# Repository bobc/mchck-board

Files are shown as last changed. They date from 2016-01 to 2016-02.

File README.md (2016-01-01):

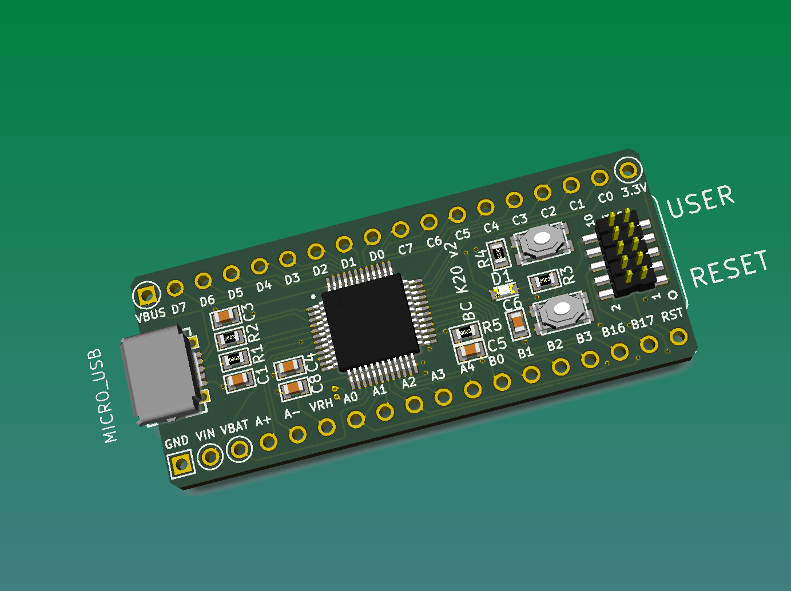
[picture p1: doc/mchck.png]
BC-HCK


About BC-HCK
============

Originally derived from mchck project. I simplified the design a lot to make more of
a bare bones board, and extended the size to get more pins at the edge.
I also incorporated ideas from TinyK20 board, the pin layout is similar (https://github.com/ErichStyger/mcuoneclipse/tree/master/tinyK20).

The schematic design and layout was done using Kicad, a Free Software EDA tool for Linux, Windows and Mac OS (http://kicad-pcb.org/download/). You will need KiCad to open the files - gEDA or Eagle will not work.

Note: this project needs the new stable version of Kicad (4.0.0 or later), previous versions can not read the new files.

KiCad

Copyright
---------
In keeping with original project, licensed with CERN OHL.

Copyright (c) 2016 Bob Cousins  
Copyright (c) 2011,2012 Simon Schubert <2@0x2c.org>

This documentation describes Open Hardware and is licensed under the
CERN OHL v. 1.1.  You may redistribute and modify this documentation
under the terms of the CERN OHL v.1.1.  You can find a copy of the
CERN OHL v.1.1 in the file LICENSE.

Fabrication outputs
-------------------

The gerbers are in the master branch in the gerbers folder.  
The zip file is for submission to ITeadMall, probably could be used for other fab houses.  
The gvp file is for use with gerbv (http://gerbv.geda-project.org/).

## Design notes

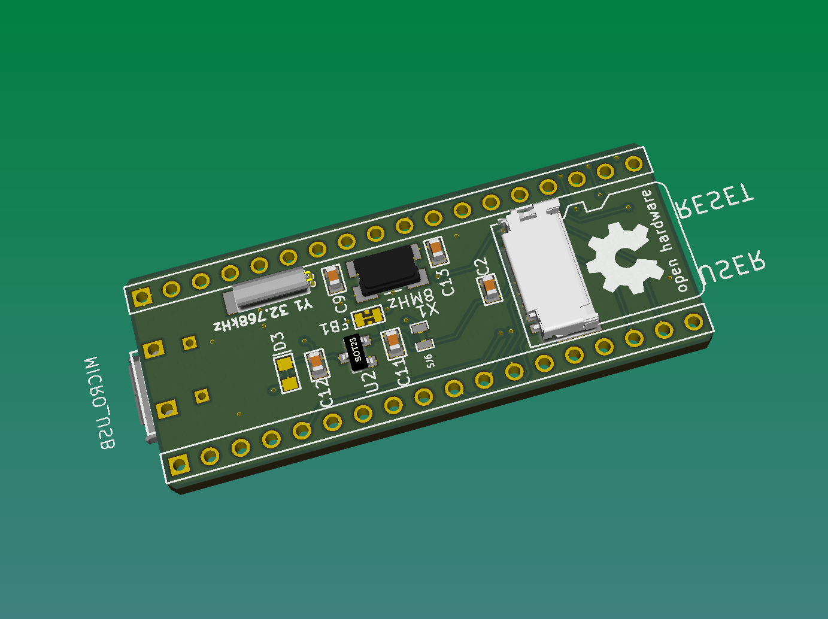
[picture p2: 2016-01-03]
doc/mchck_back.png

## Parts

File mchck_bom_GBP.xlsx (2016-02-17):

Ref | Symbol | Footprint | Value | Quantity | CPN | Manf | MPN | Farnell/Sku | Farnell/Cost | RS Components/Sku | RS Components/Cost
C1 | device:C | mchck:SM0603_Capa | 2.2u | 1 | C0603-2.2uF | Kemet | C0603C225K9PACTU | 1288257 | 0.037 | 147819 | 0.044
C2..C8 | device:C | mchck:SM0603_Capa | 100n | 6 | C0603-100nF | Kemet | C0603C104K3RACTU | 1650835 | 0.046 | 147538 | 0.108
C9..C13 | device:C | mchck:SM0603_Capa | 18pF | 2 | C0603-18pF | Kemet | C0603C180J5GACTU | 1414620 | 0.018 | 147415 | 0.038
C11..C12 | SparkFun:CAP0805 | mchck:SM0603_Capa | 10u | 2 | C0603-A-10uF | Murata | GRM188R60J106ME47D | 1735528 | 0.371 | 7235543 | 0.202
D1 | device:LED | LEDs:LED-0603 | LED | 1 | LED-0603 | Avago | HSMH-C190 | 8554641 | 0.192 | 7166570 | 0.063
D3 | SparkFun:DIODE-SCHOTTKY_ | mchck:SOD-523F-NC | DIODE-SCHOTTKY_ | 1 | D-Schottky-1A | NXP | PMEG3010EB |  |  | 8166842 | 0.070
FB1 | device:FILTER | mchck:SM0603_NC | FILTER | 1 | FB_0603 | TDK | MMZ1608B601CT |  |  | 7865015 | 0.022
G1 | logo:LOGO | mchck:OHW-LOGO-6mm | OHW LOGO | 1
J3 | conn:CONN_01X06 | RMC:USB_MICRO_RMC_FCI | MICRO_USB | 1 | USB-MICRO-FCI | FCI | 10103594-0001LF | 2293752 | 0.393 | 7142347 | 0.426
K1 | opendous:CONN_microSD | RMC:SD_MOLEX_47579-0001-2 | CONN_MICROSD | 1 | SD_MOLEX_47579-0001 | Molex | 47579-0001 |  |  | 7206028 | 0.430
P3..P4 | conn:CONN_01X18 | RMC_pcb_header:pin_header_2.54mm_1x18 | UPPER_PINS | 2 | HDR_1x18_2.54mm | Assmann | AW 108/20-T |  |  | 6742331 | 0.340
P6 | conn:CONN_02X05 | RMC:Pin_Array_5x2_SMT_1.27mm_RMC | JTAG | 1 | HDR_2x5_1.27mm | FCI | 20021121-00010C4LF | 1865279 | 0.492 | 7944584 | 0.524
R1..R2 | device:R | mchck:SM0603 | 33 | 2 | R0603-33R | Vishay | CRCW060333R0FKEA | 1469802RL | 0.021 | 6790239 | 0.022
R3 | device:R | mchck:SM0603 | 1k | 1 | R0603-1k | Vishay | CRCW06031K00FKEA | 1469740 | 0.011 | 6789875 | 0.012
R4..R5 | device:R | mchck:SM0603 | 10k | 2 | R0603-10k | Vishay | CRCW060310K0FKEA | 1469748 | 0.021 | 6789667 | 0.024
S1..S2 | tac_switchsmd_evqp2:TAC_SWITCHSMD_EVQP2 | RMC:SW_C&K_KMR4_ALT | RESET | 2 | SW-KMR4 | C&K | KMR421NGLFS | 1908235 | 0.422 | 7931605 | 0.520
SJ6 | SparkFun:SOLDERJUMPERNC | RMC:SM0603_Bridged | SOLDERJUMPERNC | 1
U1 | MK20LF:MK20LF | mchck:LQFP48 | MK20LF | 1 | IC-MK20DX128-L48 | NXP | MK20DX128VLF5 | 2133571 | 3.260 | 8181104 | 2.665
U2 | RMC:MCP1703_SOT23 | TO_SOT_Packages_SMD:SOT-23 | MCP1703_SOT23 | 1 | REG-MCP1703_SOT23 | Microchip | MCP1703T-3302E/CB | 1439518 | 0.481 | 6694907 | 0.375
X1 | RMC:XTAL_TXC_7V | Crystals:Crystal_SMD_0603_4Pads | 8MHz | 1 | XTAL-8MHz-5x3 | Abracon | ABM3B-8.000MHZ-B2 |  |  | 7031997 | 1.289
Y1 | device:Crystal | w_crystal:crystal_tc-26_horiz | 32.768kHz | 1 | XTAL-TC26H-32k | Fox | NC26LF-327 | 2064057 | 0.301 | 5476979 | 0.290

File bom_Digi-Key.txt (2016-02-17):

399-3362-6-ND,1
399-1281-1-ND,6
399-1052-1-ND,2
490-3896-1-ND,2
516-1420-6-ND,1
609-4050-6-ND,1
609-3695-1-ND,1
541-33.0HDKR-ND,10
541-1.00KHCT-ND,10
541-10.0KHCT-ND,10
KMR421NG LFS-ND,36000
MK20DX128VLF50-ND,1
MCP1703T-3302E/CBCT-ND,1
631-1205-ND,1

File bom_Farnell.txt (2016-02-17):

1288257,10
1650835,6
1414620,2
1735528,2
8554641,1
2293752,1
1865279,1
1469802RL,10
1469740,10
1469748,10
1908235,2
2133571,1
1439518,1
2064057,1

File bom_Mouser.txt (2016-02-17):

80-C0603C225K9P,1
80-C0603C104K3R,6
80-C0603C180J5G,2
81-GRM188R60J106ME47,2
630-HSMH-C190,1
649-10103594-0001LF,1
538-47579-0001,1
649-202112100010C4LF,1
71-CRCW0603-33-E3,2
71-CRCW0603-1.0K-E3,1
71-CRCW0603-10K-E3,2
841-MK20DX128VLF5,1
579-MCP1703T-3302ECB,1
559-NC26-LF,1

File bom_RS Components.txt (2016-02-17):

147819,50
147538,50
147415,50
7235543,25
7166570,10
8166842,60
7865015,100
7142347,5
7206028,1
6742331,5
7944584,5
6790239,50
6789875,50
6789667,50
7931605,2
8181104,2
6694907,10
7031997,10
5476979,10

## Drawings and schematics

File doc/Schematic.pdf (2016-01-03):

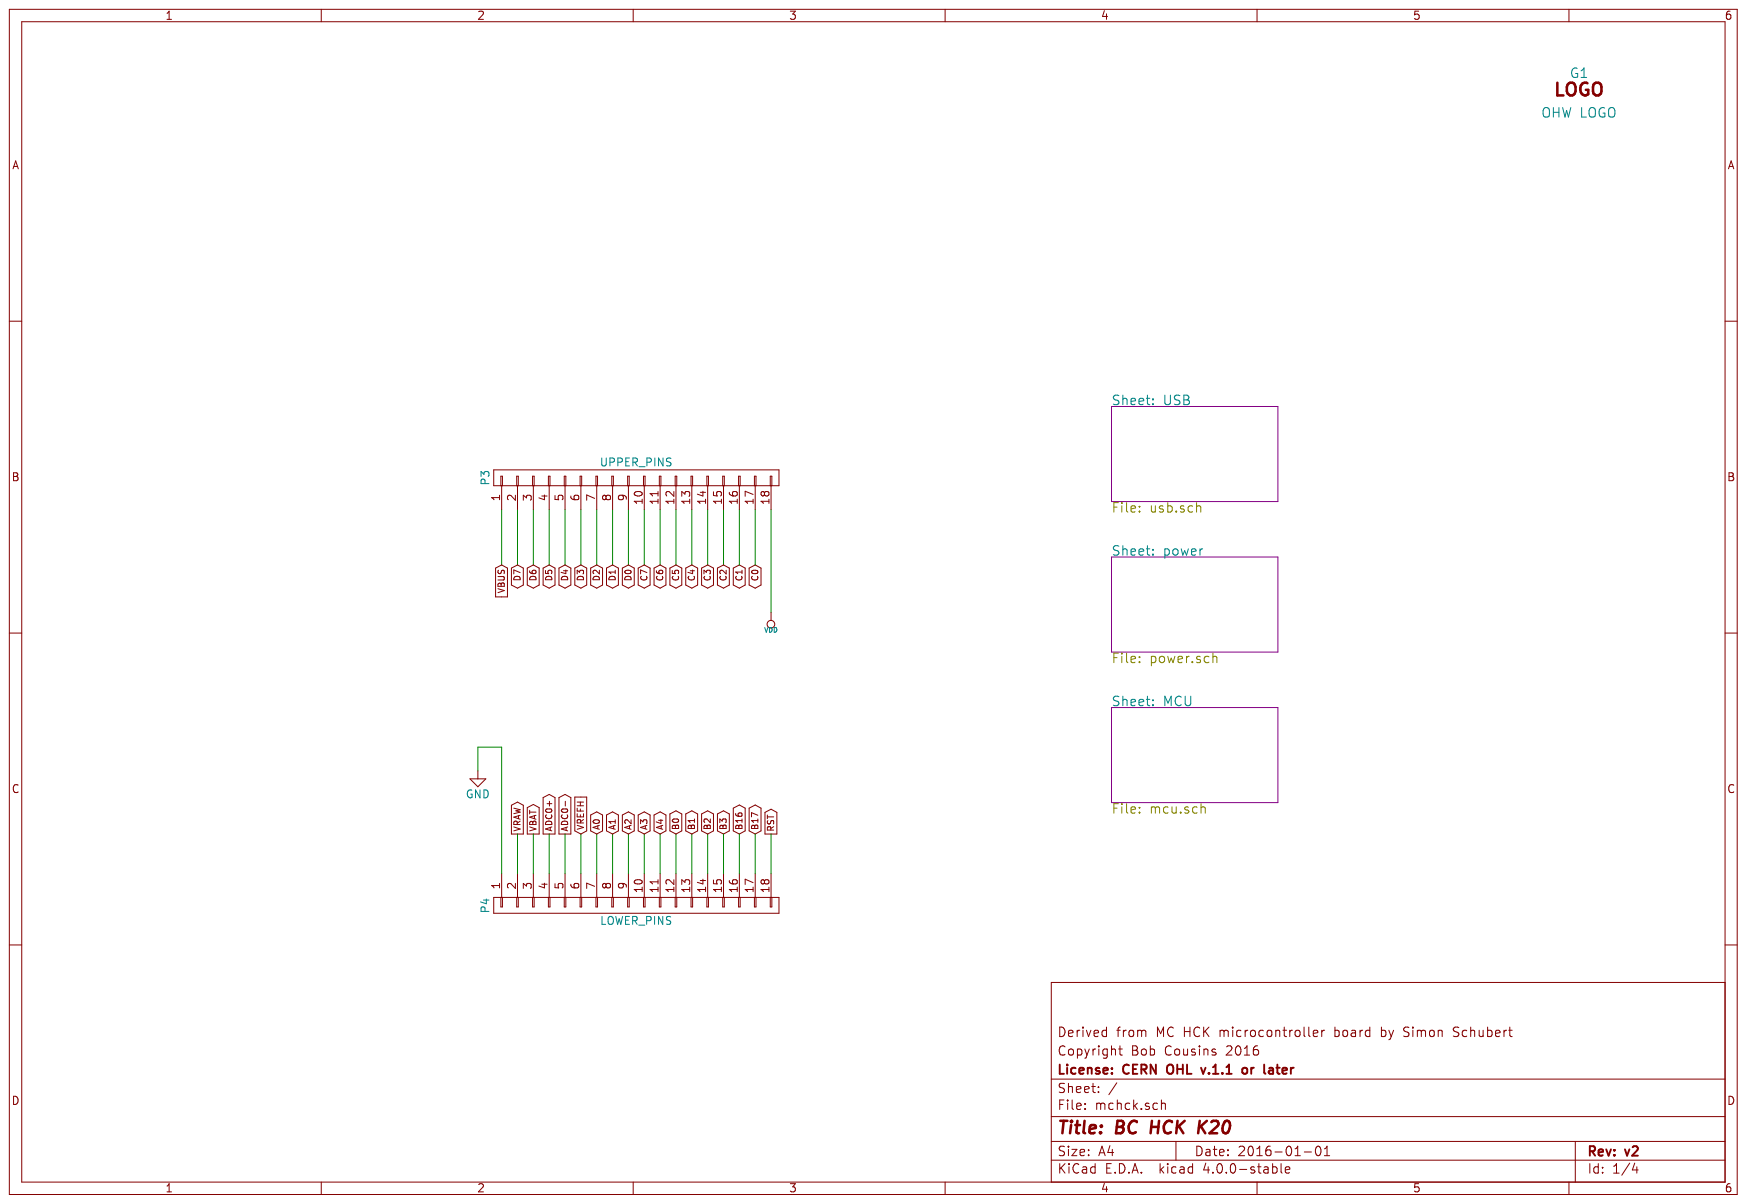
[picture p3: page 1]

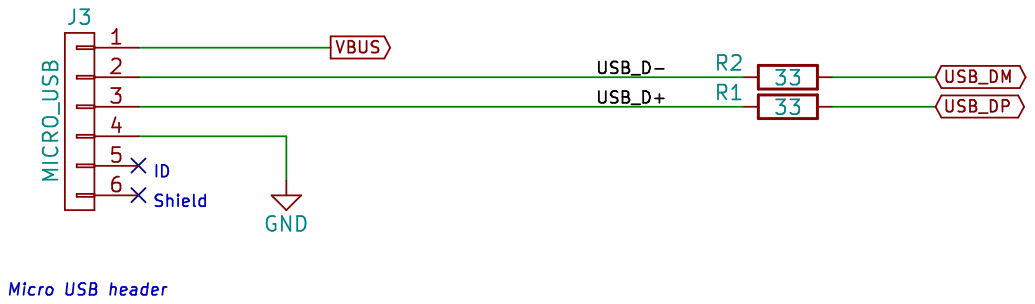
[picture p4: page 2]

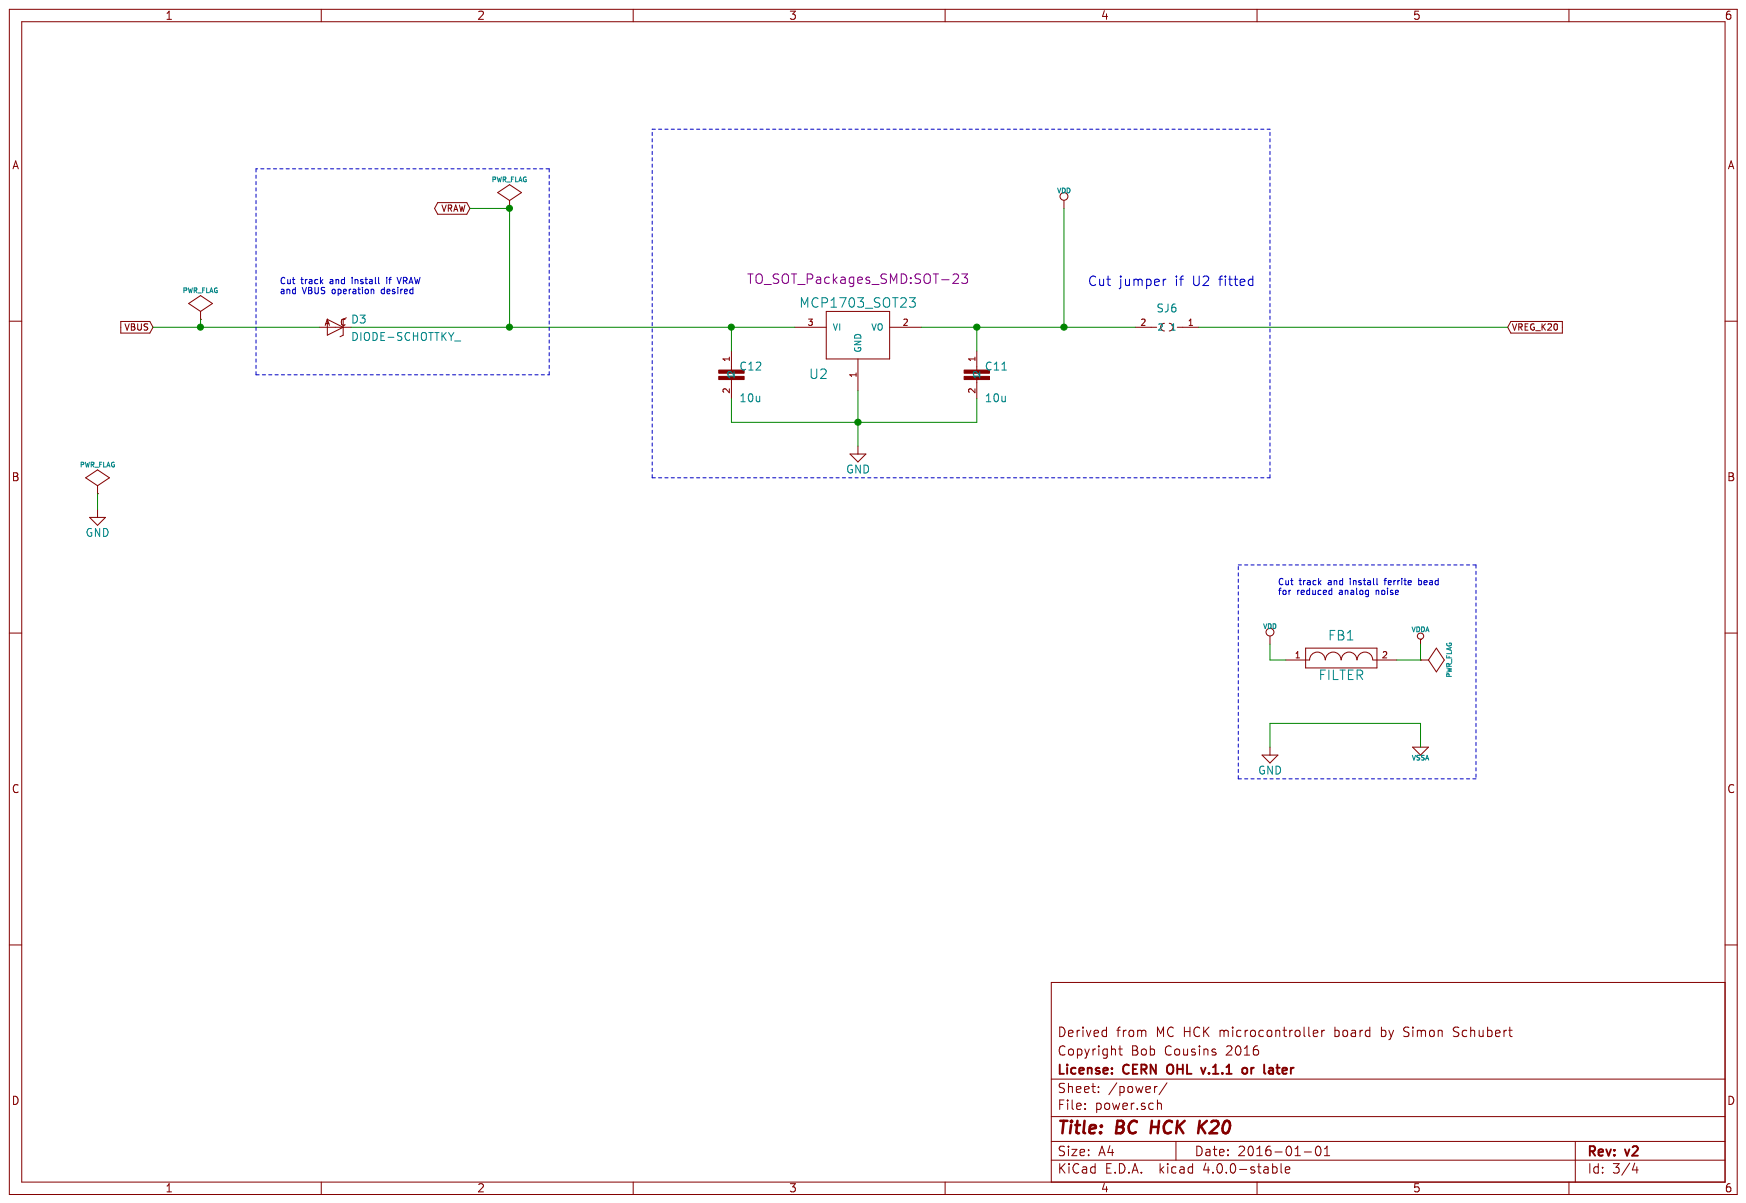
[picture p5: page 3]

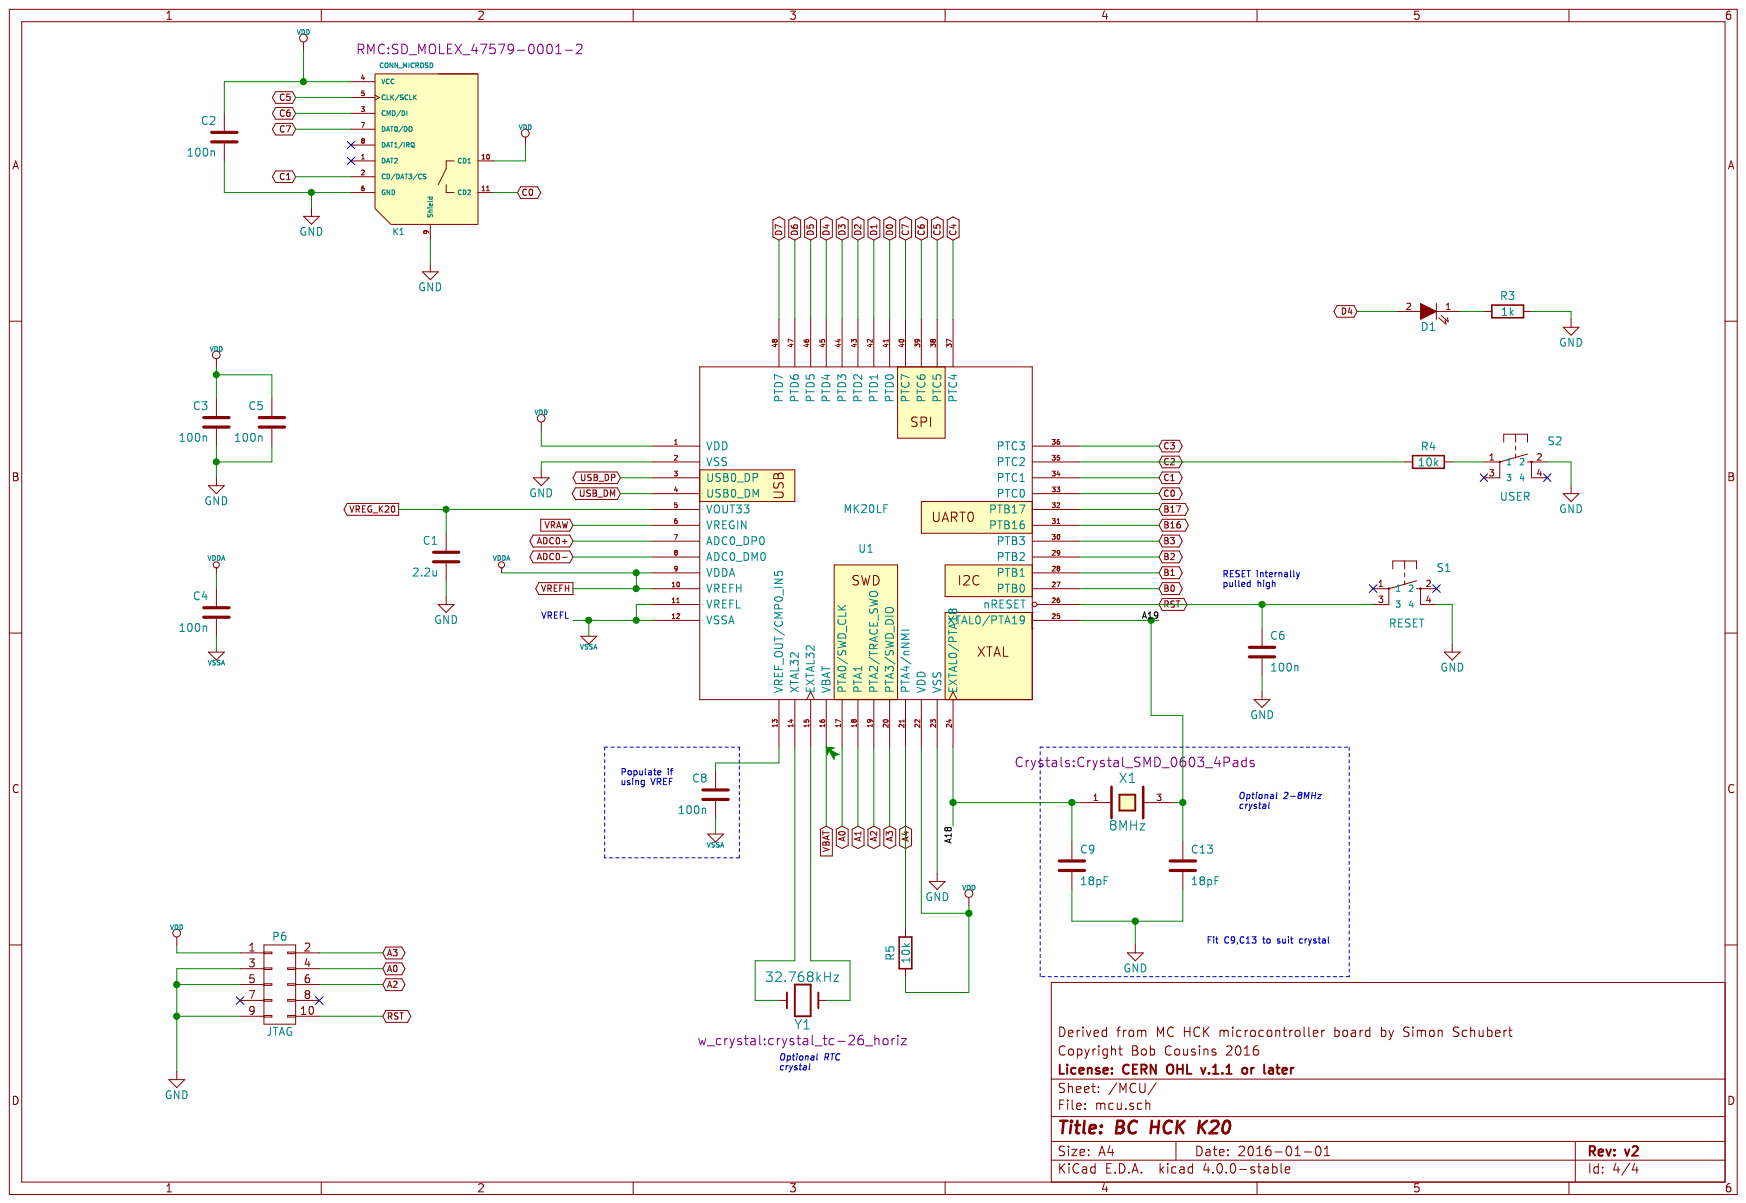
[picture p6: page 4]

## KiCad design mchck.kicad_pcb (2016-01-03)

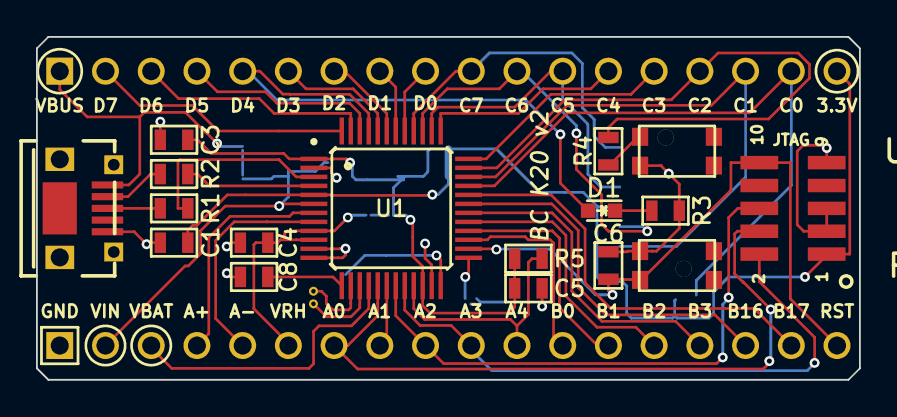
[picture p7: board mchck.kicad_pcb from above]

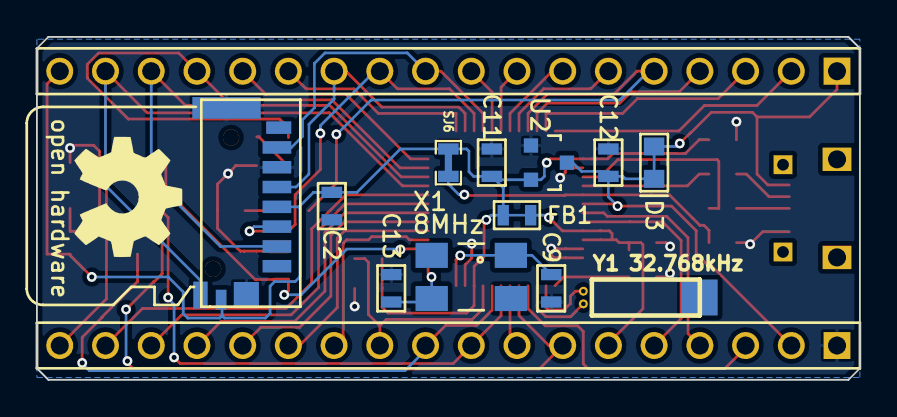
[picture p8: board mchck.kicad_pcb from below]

Board: 2 copper layers, 45.7 x 19.1 mm, 32 parts (15 on the bottom side), 48 nets.

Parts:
C1: 2.2u; SM0603_Capa
C2, C3, C4, C5, C6, C8: 100n; SM0603_Capa
C9, C13: 18pF; SM0603_Capa
C11, C12: 10u; SM0603_Capa
D1: LED; LED-0603
D3: DIODE-SCHOTTKY_; SOD-523F-NC
FB1: FILTER; SM0603_NC
G1: OHW LOGO; OHW-LOGO-6mm
J3: MICRO_USB; USB_MICRO_RMC_FCI
K1: CONN_MICROSD; SD_MOLEX_47579-0001-2
P3: UPPER_PINS; pin_header_2.54mm_1x18
P4: LOWER_PINS; pin_header_2.54mm_1x18
P6: JTAG; Pin_Array_5x2_SMT_1.27mm_RMC
R1, R2: 33; SM0603
R3: 1k; SM0603
R4, R5: 10k; SM0603
S1: RESET; SW_C&K_KMR4_ALT
S2: USER; SW_C&K_KMR4_ALT
SJ6: SOLDERJUMPERNC; SM0603_Bridged
U1: MK20LF; LQFP48
U2: MCP1703_SOT23; SOT-23
X1: 8MHz; Crystal_SMD_0603_4Pads
Y1: 32.768kHz; crystal_tc-26_horiz

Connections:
/MCU/A18: C9.1, U1.24, X1.1
/MCU/A19: C13.1, U1.25, X1.3
/USB/USB_D+: J3.3, R1.1
/USB/USB_D-: J3.2, R2.1
A0: P4.7, P6.4, U1.17
A1: P4.8, U1.18
A2: P4.9, P6.6, U1.19
A3: P4.10, P6.2, U1.20
A4: P4.11, R5.2, U1.21
ADC0+: P4.4, U1.7
ADC0-: P4.5, U1.8
B0: P4.12, U1.27
B1: P4.13, U1.28
B2: P4.14, U1.29
B3: P4.15, U1.30
B16: P4.16, U1.31
B17: P4.17, U1.32
C0: K1.11, P3.17, U1.33
C1: K1.2, P3.16, U1.34
C2: P3.15, R4.1, U1.35
C3: P3.14, U1.36
C4: P3.13, U1.37
C5: K1.5, P3.12, U1.38
C6: K1.3, P3.11, U1.39
C7: K1.7, P3.10, U1.40
D0: P3.9, U1.41
D1: P3.8, U1.42
D2: P3.7, U1.43
D3: P3.6, U1.44
D4: D1.2, P3.5, U1.45
D5: P3.4, U1.46
D6: P3.3, U1.47
D7: P3.2, U1.48
GND: C1.2, C2.2, C3.2, C4.2, C5.2, C6.2, C8.2, C9.2, C11.2, C12.2, C13.2, J3.4, K1.6, K1.9, P4.1, P6.3, P6.5, P6.9, R3.2, S1.4, S2.2, U1.2, U1.11, U1.12, U1.23, U2.1
unnamed: C8.1, U1.13
unnamed: D1.1, R3.1
unnamed: R4.2, S2.1
unnamed: U1.14, Y1.2
unnamed: U1.15, Y1.1
RST: C6.1, P4.18, P6.10, S1.3, U1.26
USB_DM: R2.2, U1.4
USB_DP: R1.2, U1.3
VBAT: P4.3, U1.16
VBUS: D3.A, J3.1, P3.1
VDD: C2.1, C3.1, C5.1, C11.1, FB1.1, K1.4, K1.10, P3.18, P6.1, R5.1, SJ6.2, U1.1, U1.22, U2.2
VRAW: C12.1, D3.C, P4.2, U1.6, U2.3
VREFH: C4.1, FB1.2, P4.6, U1.9, U1.10
VREG_K20: C1.1, SJ6.1, U1.5

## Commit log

2015-12-14 Mash up of MCHCK with TinyK20-like pinout
    [mchck.kicad_pcb, mchck.sch, mcu.sch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]
2015-12-20 Move standard schematic libraries to library folder
2016-01-01 Fix up libs and footprints for Kicad v4; remove several unused libs
    [mchck.kicad_pcb, mchck.sch, mcu.sch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]
2016-01-01 Add missing schematic libs
2016-01-01 Add missing footprints; convert for Kicad v4
2016-01-01 Add gerber files
    [mchck-B.Cu.gbl, mchck-B.Mask.gbs, mchck-B.SilkS.gbo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]
2016-01-01 Remove some unused files
    [charger.sch]
2016-01-01 Tidy up some texts; add doc files
    [mchck.kicad_pcb, mchck.sch, mcu.sch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]
2016-01-01 Add 3d model for IC
    [mchck.kicad_pcb]
2016-01-01 Add KiCad badge
2016-01-03 Final tidy up for V2.
    [mchck-B.Cu.gbl, mchck-B.Mask.gbs, mchck-B.SilkS.gbo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]
2016-02-17 Added BOMs for popular suppliers
    [mchck_bom_GBP.xlsx, mchck_bom_USD.xlsx]

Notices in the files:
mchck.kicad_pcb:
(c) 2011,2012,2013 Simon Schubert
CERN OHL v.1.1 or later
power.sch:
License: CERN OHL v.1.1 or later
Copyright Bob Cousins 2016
